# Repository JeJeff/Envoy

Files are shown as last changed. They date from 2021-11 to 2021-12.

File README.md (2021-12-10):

# Envoy
Envoy is a numberpad that can also be built as a 20 key macropad with support for four encoders. 
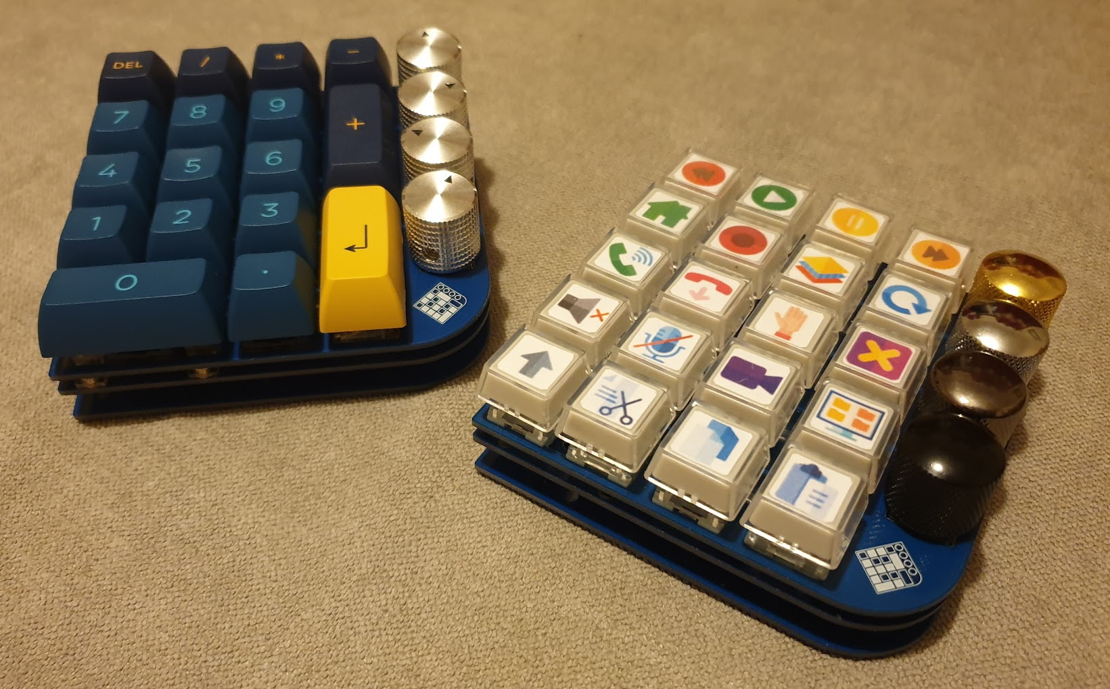
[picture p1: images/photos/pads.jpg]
Envoy numberpad and macropad


<details>
  <summary>Kicad images</summary>
  
 ### PCB Front
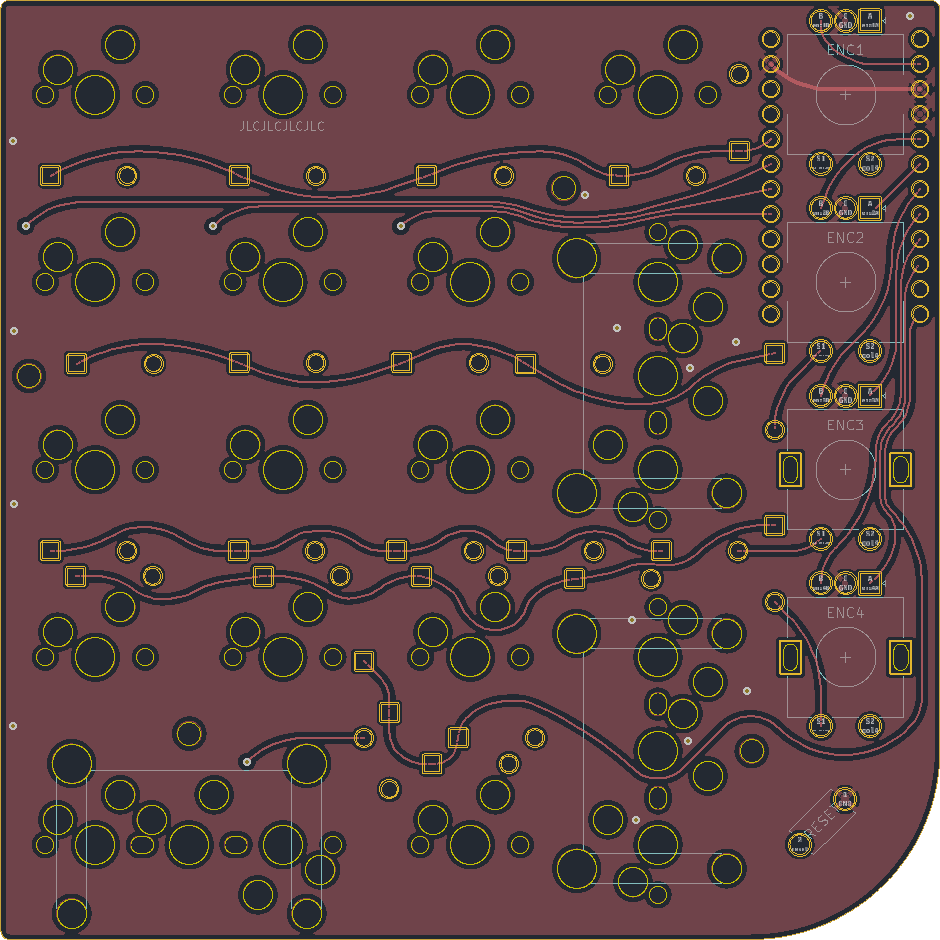
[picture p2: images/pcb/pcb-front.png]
Front of PCB
 
 
 ### PCB Back
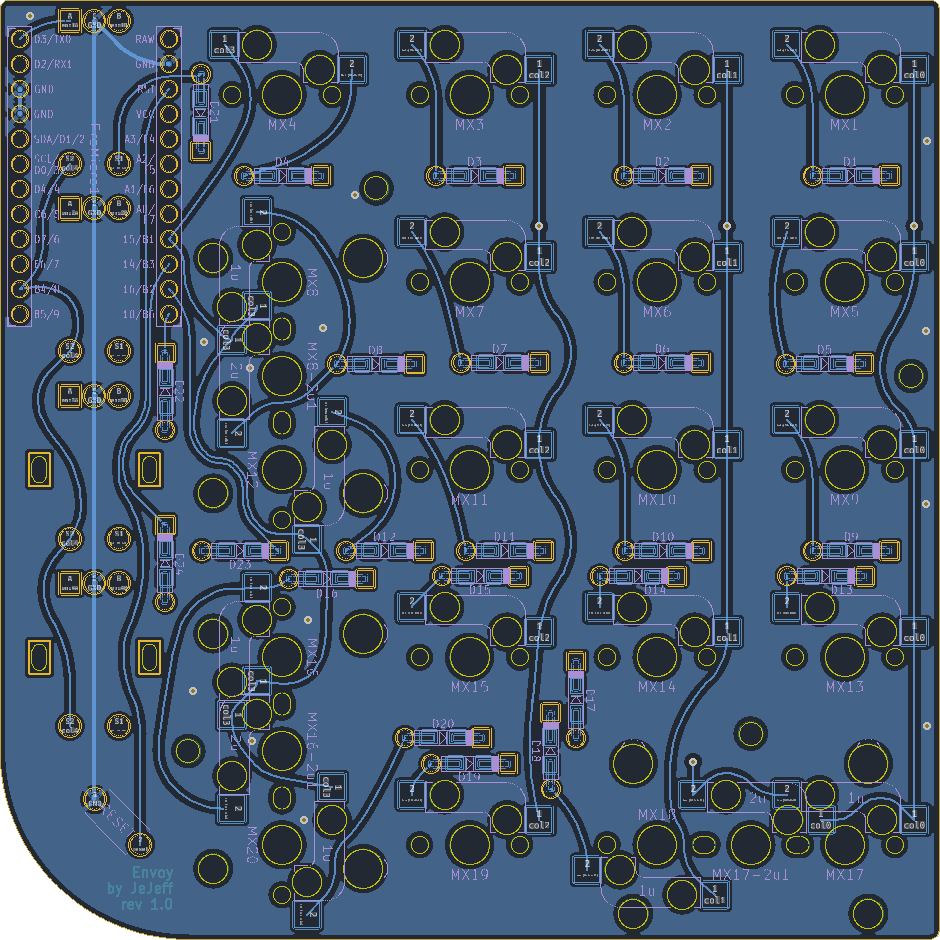
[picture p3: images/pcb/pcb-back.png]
Back of PCB
 
</details>

<details>
  <summary>PCB renders</summary>
  
 ### PCB Front
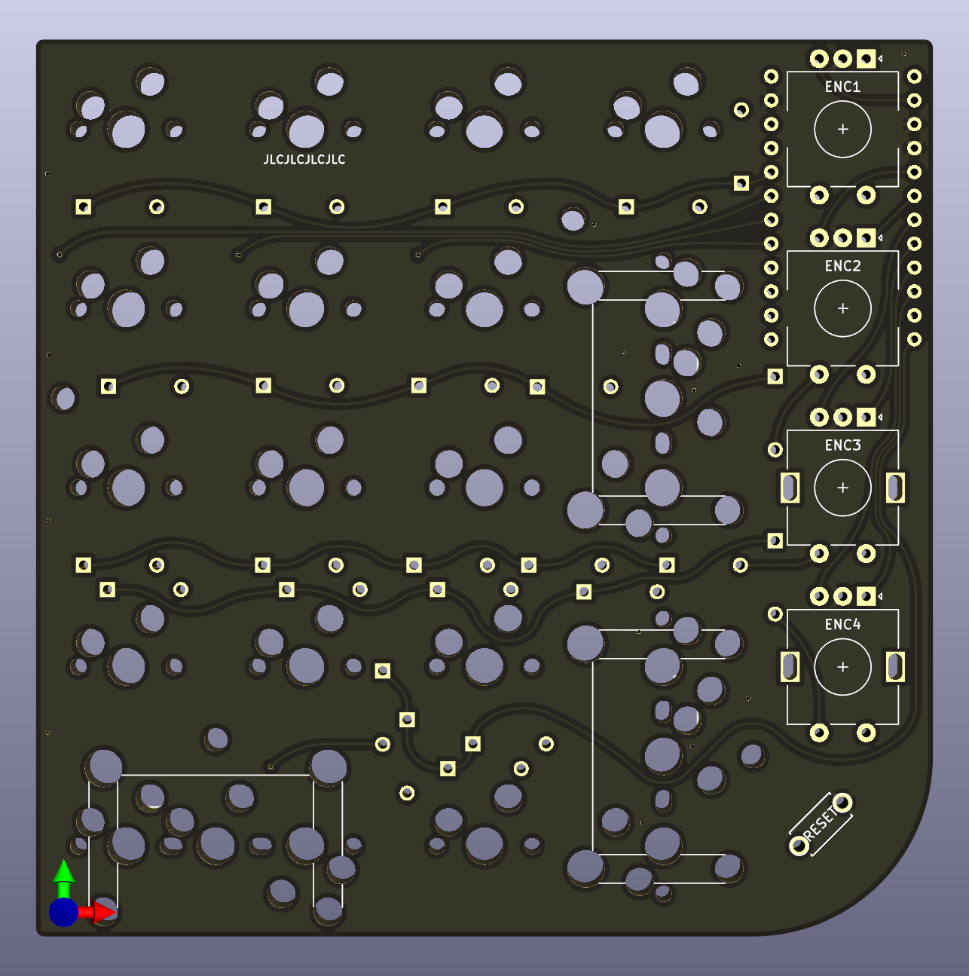
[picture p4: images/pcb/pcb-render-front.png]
Front of PCB
 
 
 ### PCB Back
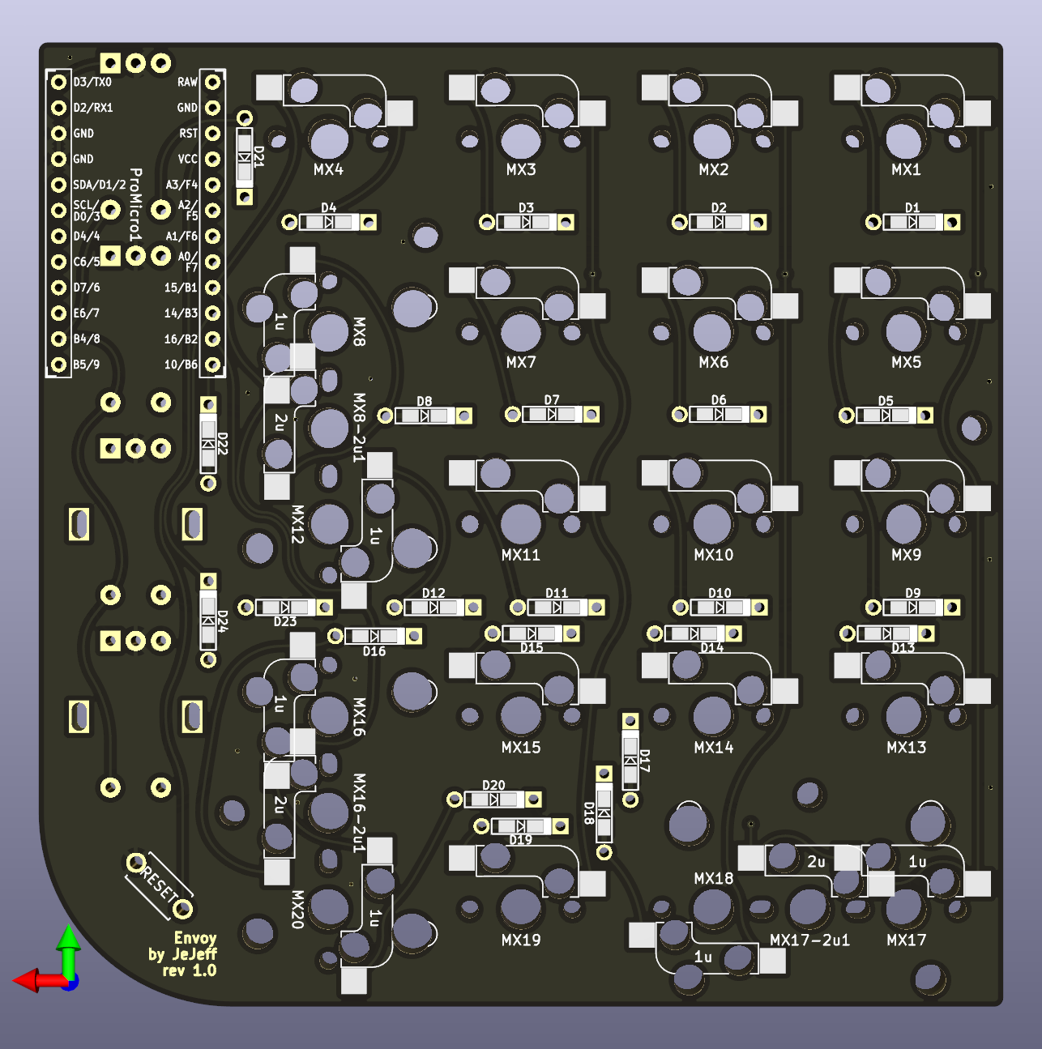
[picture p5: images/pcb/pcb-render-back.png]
Back of PCB
 
</details>

## Key features
* 20 key macro pad or standard number pad configuration
* Both 3 and 5 pin MX style switches supported
* Hot swap sockets
* Four rotary encoders
* QMK controlled
* Vial firmware
* Easy to solder

## Additional information
 * 2 layer PCB
 * Switch plate and back plate designs available
 * Both throughhole and SMD diodes supported
 
## Bill of materials
|Reference | Item | Quantity | Notes
|:---:|---|:---:|---
| | **Plates** | |
| | PCB | 1 |
| | Back plate | 1 | 
| | Switch plate | 1 | Technically optional, but recommended.
| | | |
| | **Components to solder** | |
| D1-D20 | 1N4148 Diode | 21-24 | Both SMD (SOD-123) and through hole (DO-35) supported.
| U1 | 12x1 male pin header | 2 | For the pro micro.
| U1 | Pro Micro | 1 | Or pin compatible controller.
| ENC1-ENC4| EC11 Rotary Encoder | 4 | 
| | | |
| | **Hardware** | |
| | Aluminium cone feet | 0 or 2 | If you want to raise the back and tilt the pad towards you.
| | M2 standoff 8mm | 4 | 
| | M2 x 6mm flat head screw | 8 | Button head screws also work, could go as short as 4mm.
| | Rubber feet 8mm diameter | 2 or 4 | Only 2 needed if also using the cone feet.
| | | |
| | **Keys and Knobs** | |
| | 2u Stabilizer | 0-3 | One required for each 2u key, 3 for a standard number pad configuration.
| | MX Switches | 17-20 | 
| | Keycaps | 17-20 | 
| | Encoder knob | 4 | Matching the encoder, max diameter 18mm.

## Build Guide
* [Long version with descriptions and tips](Build-Guide.md) 
* [Short version which is not much more than a list of steos](Build-Guide-Short.md)

## Firmware
[See the firmware flashing guide](Firmware/Firmware-Flashing.md)

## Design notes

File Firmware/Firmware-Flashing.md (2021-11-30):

### Envoy Firmware Flashing Guide
Use [QMK Toolbox](https://github.com/qmk/qmk_toolbox/releases) to flash the firmware.

1. Download the [recommended vial firmware here](https://github.com/JeJeff/Envoy/raw/main/Firmware/jejeff_envoy_vial.hex) (right click > save link as...). 
2. Open the QMK Toolbox application.
3. Under 'local file' select the downloaded jejeff_envoy_vial.hex file.
4. Set the MCU field to 'atmega32u4'.
5. Connect your the Pro Micro to your computer using USB.  You may need to wait whilst your operating system installs drivers.
6. Short the two 'reset' pins on the rounded corner of the PCB.  You could use tweezers, or a short length of wire.
7. You should see the yellow text that starts ```*** Caterina device connected``` appear
8. Click the 'Flash' button within 8 seconds.
9. Wait as QMK Toolbox reads the Pro Micro, writes the new firmware, then verifies it was successful.
10. Near the bottom you should get confirmation that it was verified successfully:
```
    avrdude.exe: verifying ...
    avrdude.exe: 24920 bytes of flash verified
    
    avrdude.exe done.  Thank you.
```
11. Your Envoy macro pad is now ready to be configured in [Vial](https://get.vial.today/).

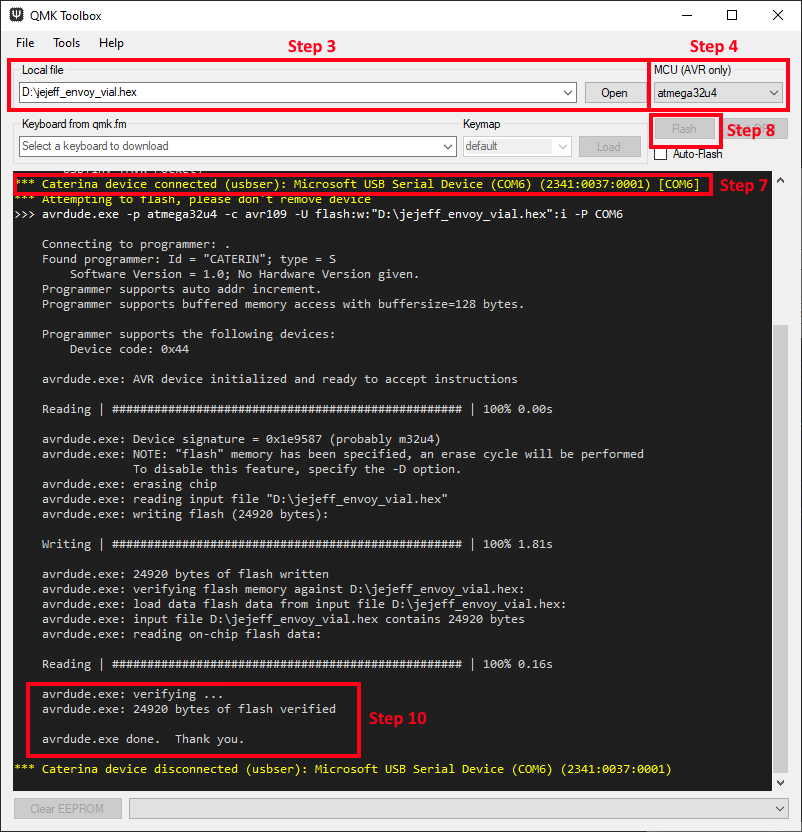
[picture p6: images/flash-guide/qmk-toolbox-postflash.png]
QMK Toolbox window annotated with the above steps


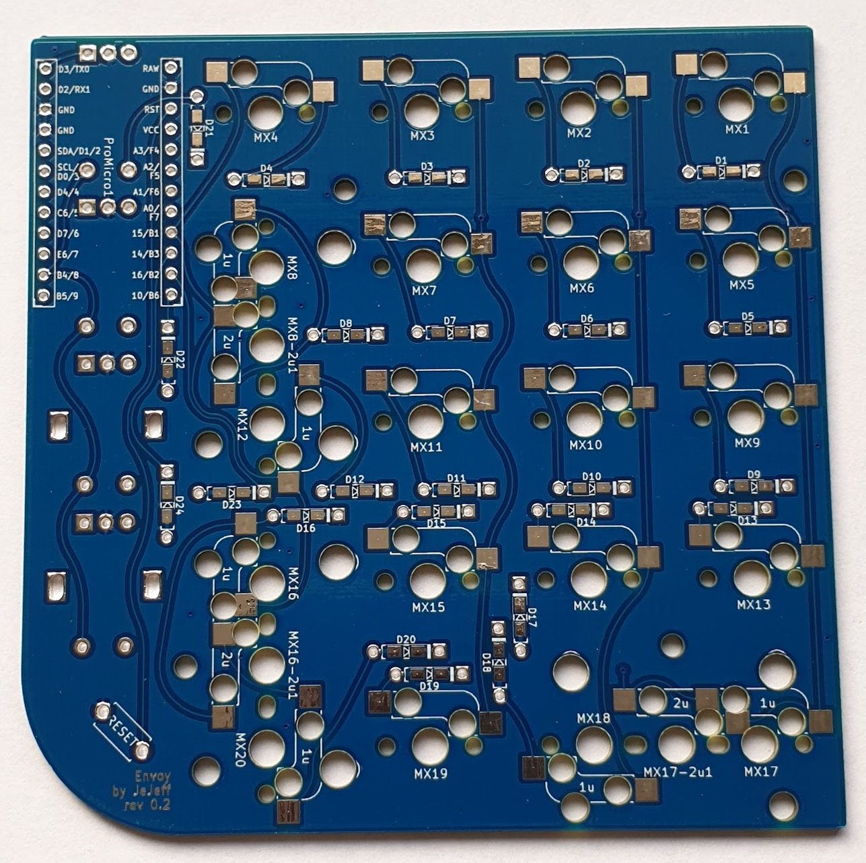
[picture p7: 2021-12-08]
images/photos/pcb-back.jpg

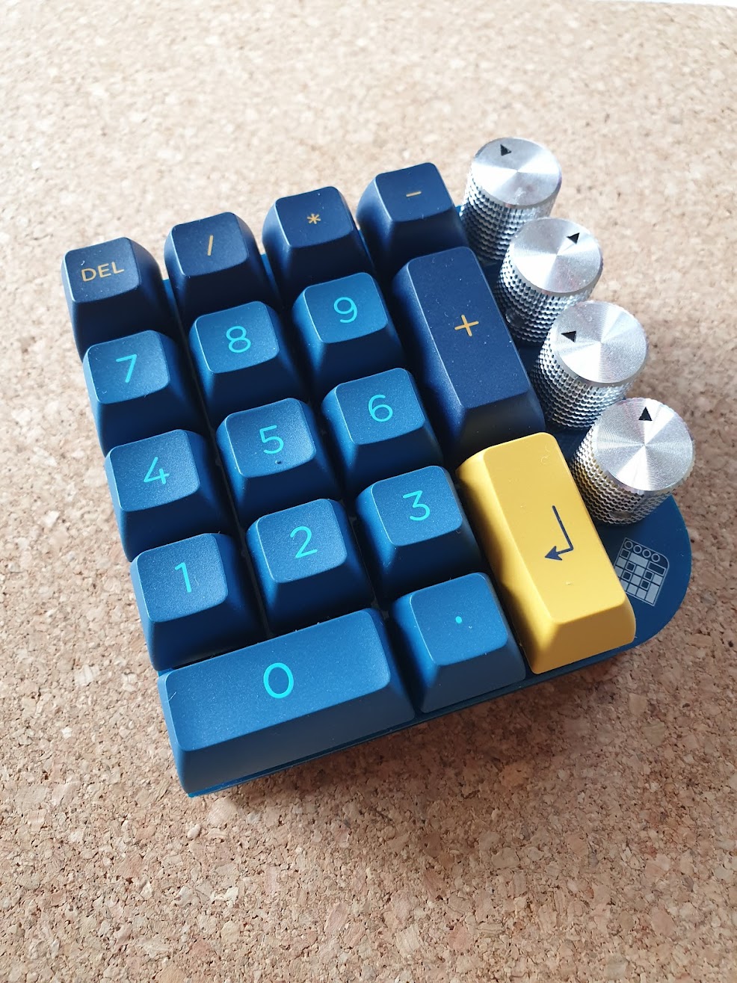
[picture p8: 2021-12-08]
images/photos/numberpad.jpg

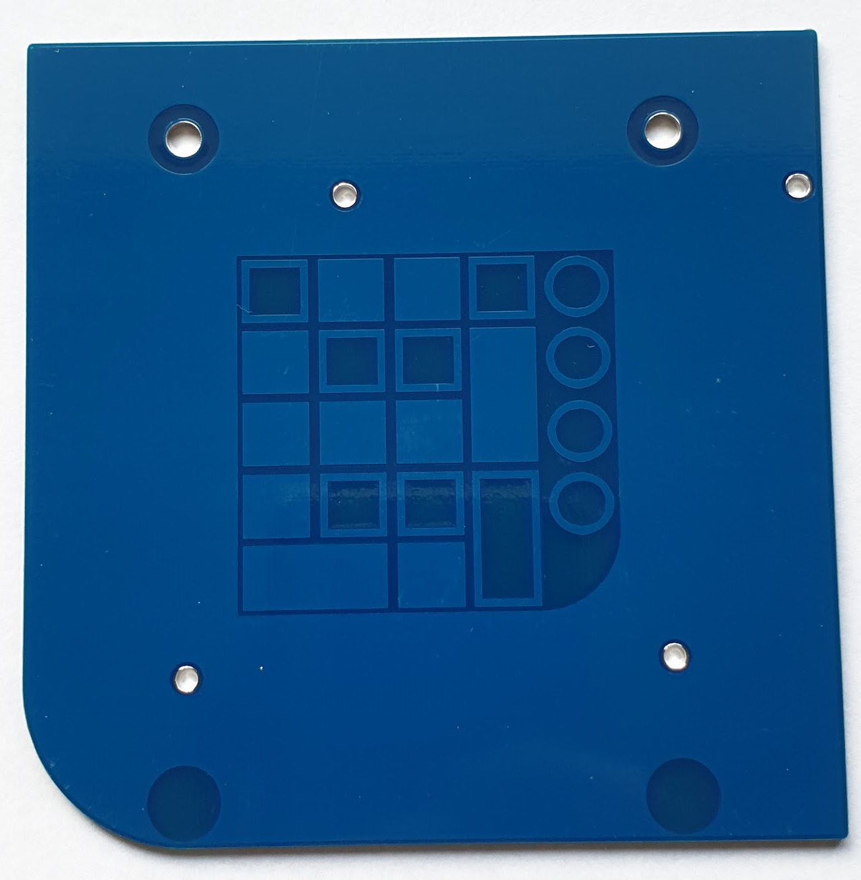
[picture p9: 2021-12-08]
images/photos/backplate-back.jpg

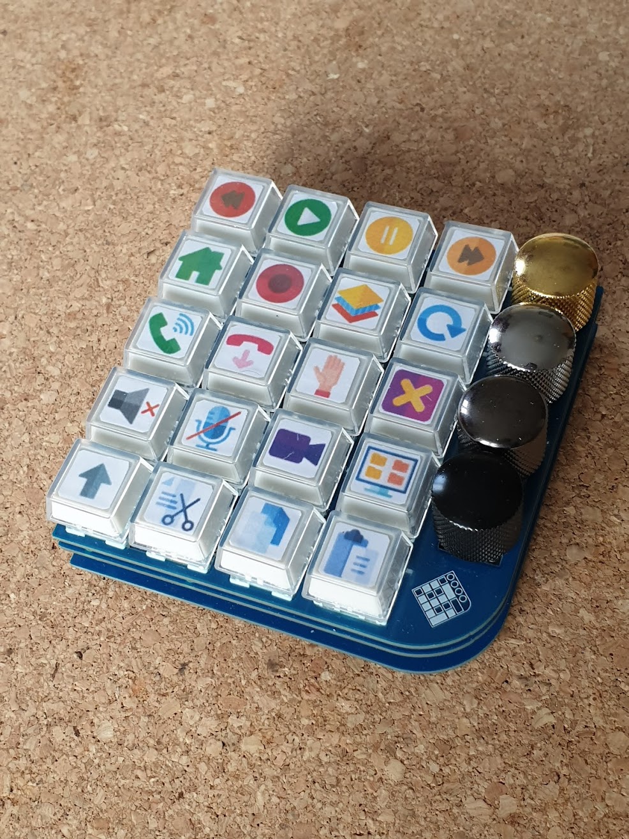
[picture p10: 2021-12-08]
images/photos/macropad.jpg

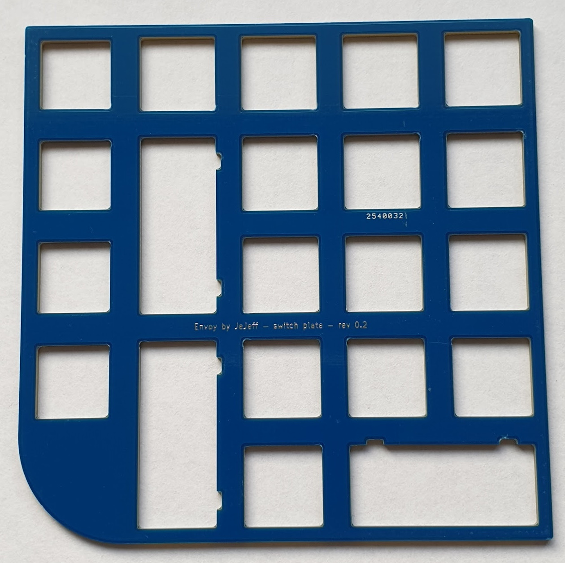
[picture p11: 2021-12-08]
images/photos/switchplate-back.jpg

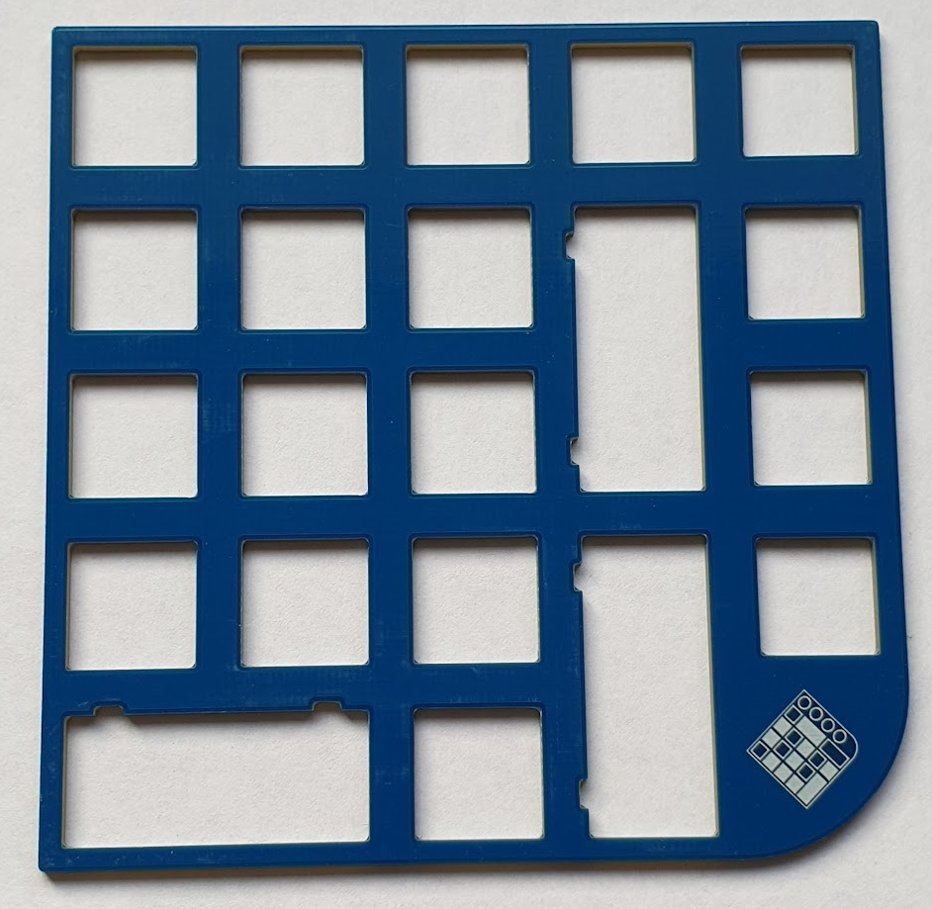
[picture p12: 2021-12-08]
images/photos/switchplate-front.jpg

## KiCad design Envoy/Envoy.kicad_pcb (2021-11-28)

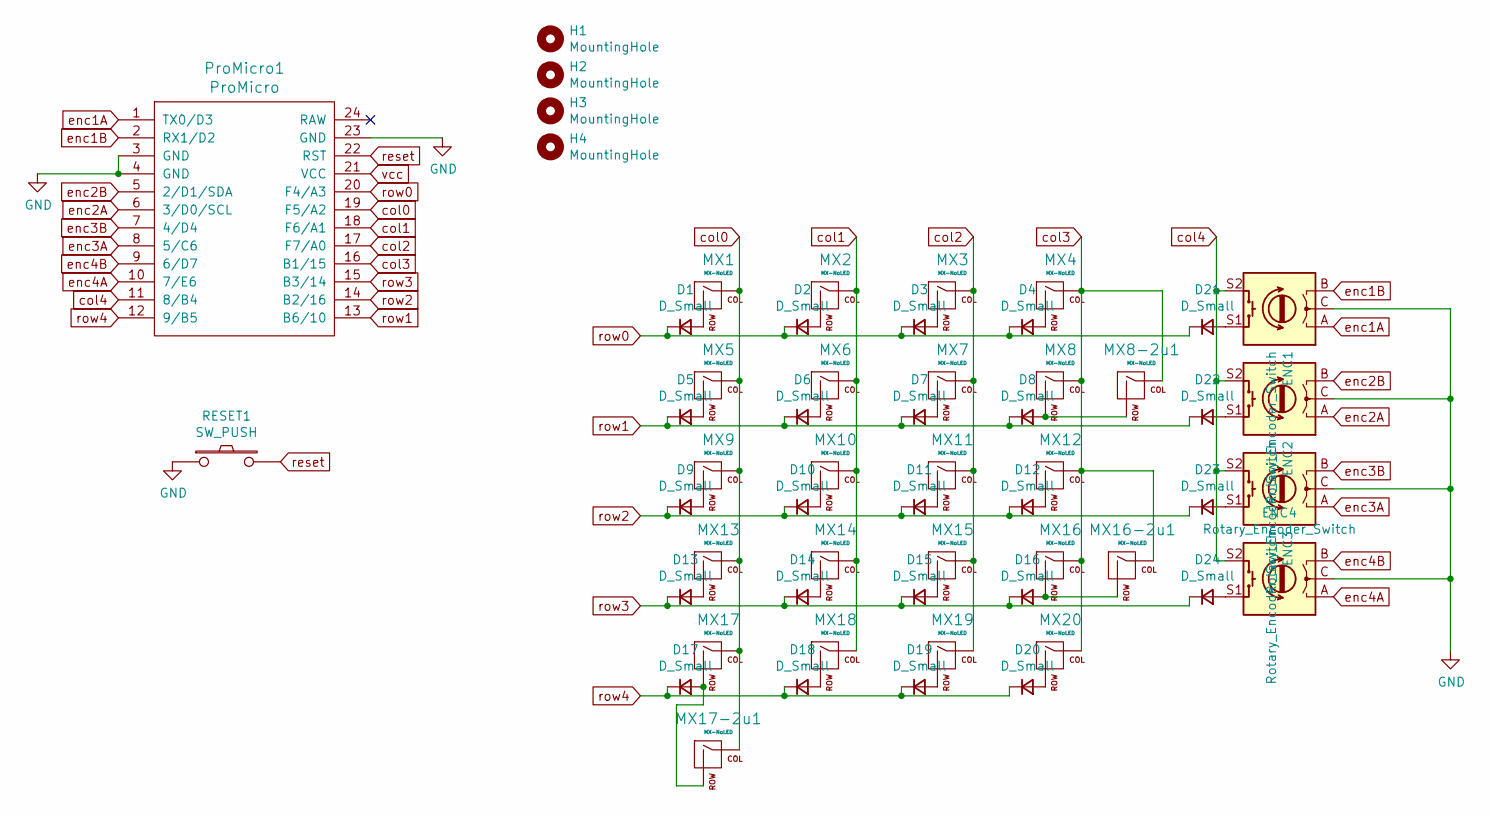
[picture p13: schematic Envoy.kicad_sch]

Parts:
D1, D2, D3, D4, D5, D6, D7, D8, D9, D10, D11, D12, D13, D14, D15, D16, D17, D18, D19, D20, D21, D22, D23, D24: D_Small; Diode-Hybrid-Back
ENC1, ENC2: Rotary_Encoder_Switch; RotaryEncoder_EC11-no-legs
ENC3, ENC4: Rotary_Encoder_Switch; RotaryEncoder_EC11
H1, H2, H3, H4: MountingHole; MountingHole_2.5mm
MX1, MX2, MX3, MX5, MX6, MX7, MX9, MX10, MX11, MX13, MX14, MX15, MX19: MX-NoLED; MXOnly-1U-Hotswap
MX4: MX-NoLED; MXOnly-1U-HotswapReversed
MX8, MX12, MX16, MX17: MX-NoLED; MXOnly-1U-Hotswap-2KeyAlternativeLeft
MX8-2u1, MX16-2u1: MX-NoLED; MXOnly-2U-Hotswap-2KeyAlternative
MX17-2u1: MX-NoLED; MXOnly-2U-Hotswap-ReversedStabilizers-Alternative
MX18, MX20: MX-NoLED; MXOnly-1U-HotswapReversed-2KeyAlternativeLeft
ProMicro1: ProMicro; ProMicro_v3
RESET1: SW_PUSH; ResetSW

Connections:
GND: ENC1.C, ENC2.C, ENC3.C, ENC4.C, ProMicro1.3 (GND), ProMicro1.4 (GND), ProMicro1.23 (GND), RESET1.1
unnamed: D1.2 (A), MX1.2 (ROW)
unnamed: D2.2 (A), MX2.2 (ROW)
unnamed: D3.2 (A), MX3.2 (ROW)
unnamed: D4.2 (A), MX4.2 (ROW)
unnamed: D5.2 (A), MX5.2 (ROW)
unnamed: D6.2 (A), MX6.2 (ROW)
unnamed: D7.2 (A), MX7.2 (ROW)
unnamed: D8.2 (A), MX8.2 (ROW), MX8-2u1.2 (ROW)
unnamed: D9.2 (A), MX9.2 (ROW)
unnamed: D10.2 (A), MX10.2 (ROW)
unnamed: D11.2 (A), MX11.2 (ROW)
unnamed: D12.2 (A), MX12.2 (ROW)
unnamed: D13.2 (A), MX13.2 (ROW)
unnamed: D14.2 (A), MX14.2 (ROW)
unnamed: D15.2 (A), MX15.2 (ROW)
unnamed: D16.2 (A), MX16.2 (ROW), MX16-2u1.2 (ROW)
unnamed: D17.2 (A), MX17.2 (ROW), MX17-2u1.2 (ROW)
unnamed: D18.2 (A), MX18.2 (ROW)
unnamed: D19.2 (A), MX19.2 (ROW)
unnamed: D20.2 (A), MX20.2 (ROW)
unnamed: D21.2 (A), ENC1.S1
unnamed: D22.2 (A), ENC2.S1
unnamed: D23.2 (A), ENC3.S1
unnamed: D24.2 (A), ENC4.S1
col0: MX1.1 (COL), MX5.1 (COL), MX9.1 (COL), MX13.1 (COL), MX17.1 (COL), MX17-2u1.1 (COL), ProMicro1.19 (F5/A2)
col1: MX2.1 (COL), MX6.1 (COL), MX10.1 (COL), MX14.1 (COL), MX18.1 (COL), ProMicro1.18 (F6/A1)
col2: MX3.1 (COL), MX7.1 (COL), MX11.1 (COL), MX15.1 (COL), MX19.1 (COL), ProMicro1.17 (F7/A0)
col3: MX4.1 (COL), MX8.1 (COL), MX8-2u1.1 (COL), MX12.1 (COL), MX16.1 (COL), MX16-2u1.1 (COL), MX20.1 (COL), ProMicro1.16 (B1/15)
col4: ENC1.S2, ENC2.S2, ENC3.S2, ENC4.S2, ProMicro1.11 (8/B4)
enc1A: ENC1.A, ProMicro1.1 (TX0/D3)
enc1B: ENC1.B, ProMicro1.2 (RX1/D2)
enc2A: ENC2.A, ProMicro1.6 (3/D0/SCL)
enc2B: ENC2.B, ProMicro1.5 (2/D1/SDA)
enc3A: ENC3.A, ProMicro1.8 (5/C6)
enc3B: ENC3.B, ProMicro1.7 (4/D4)
enc4A: ENC4.A, ProMicro1.10 (7/E6)
enc4B: ENC4.B, ProMicro1.9 (6/D7)
reset: ProMicro1.22 (RST), RESET1.2
row0: D1.1 (K), D2.1 (K), D3.1 (K), D4.1 (K), D21.1 (K), ProMicro1.20 (F4/A3)
row1: D5.1 (K), D6.1 (K), D7.1 (K), D8.1 (K), D22.1 (K), ProMicro1.13 (B6/10)
row2: D9.1 (K), D10.1 (K), D11.1 (K), D12.1 (K), D23.1 (K), ProMicro1.14 (B2/16)
row3: D13.1 (K), D14.1 (K), D15.1 (K), D16.1 (K), D24.1 (K), ProMicro1.15 (B3/14)
row4: D17.1 (K), D18.1 (K), D19.1 (K), D20.1 (K), ProMicro1.12 (9/B5)
vcc: ProMicro1.21 (VCC)

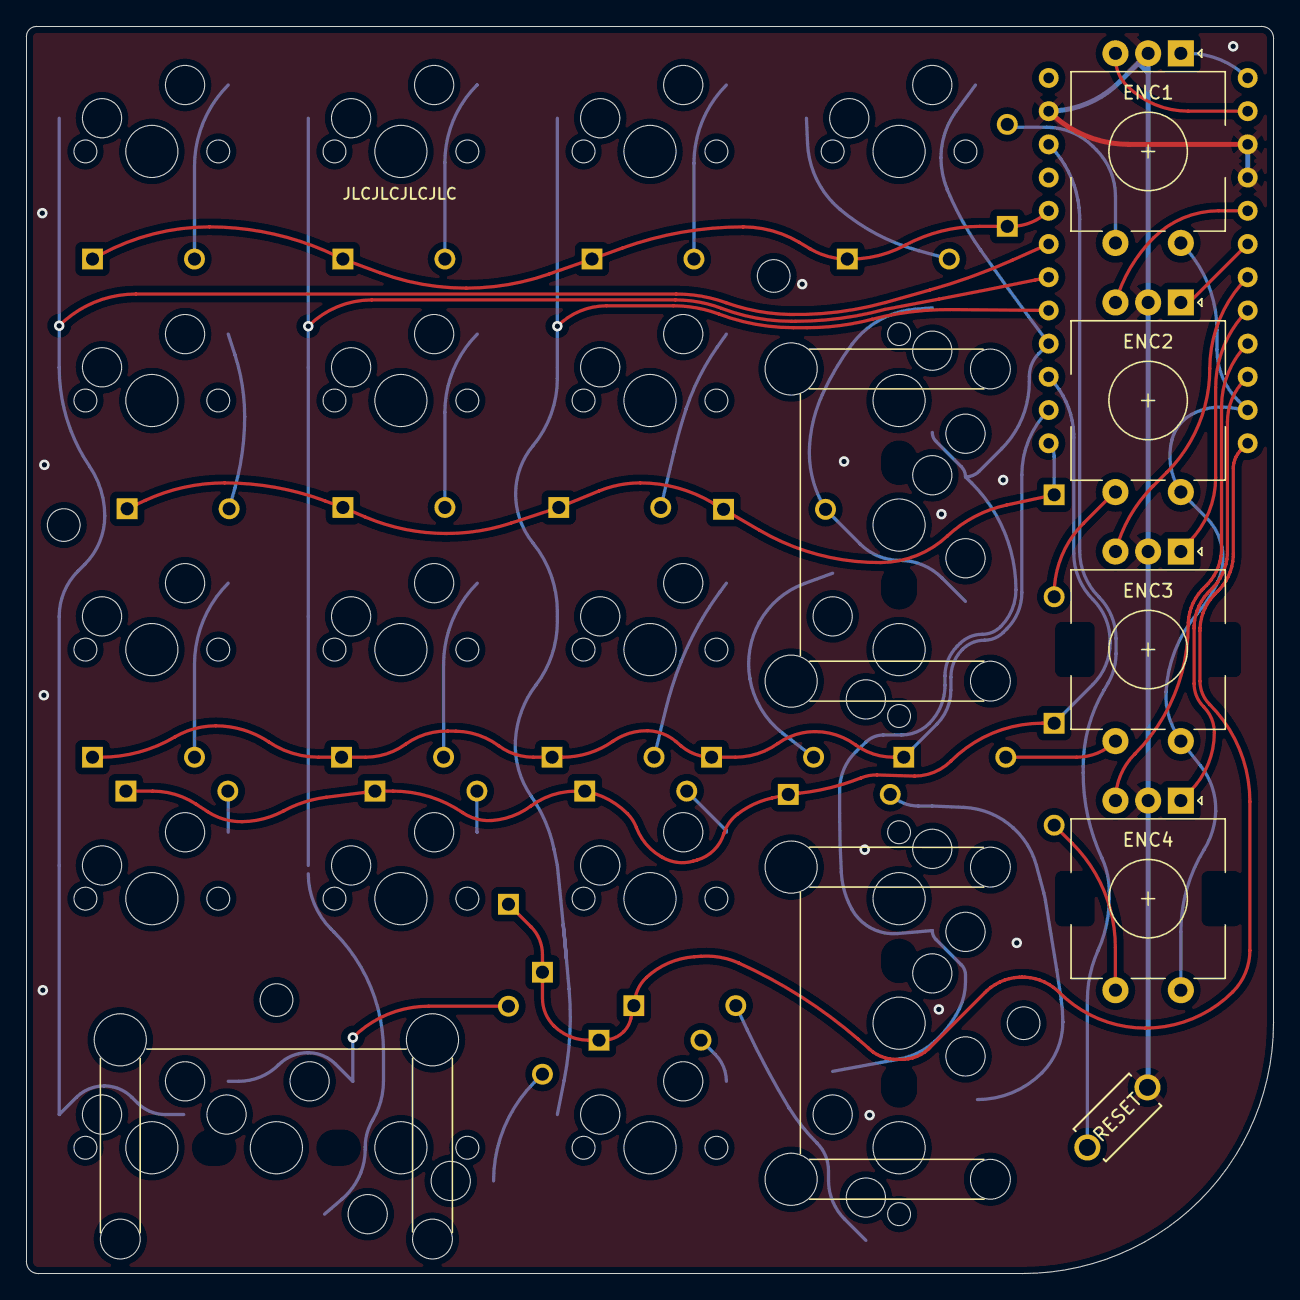
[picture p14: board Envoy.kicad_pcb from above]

Board: 2 copper layers, 95.4 x 95.4 mm, 57 parts (0 on the bottom side), 44 nets.

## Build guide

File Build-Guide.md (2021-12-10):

# Envoy macro pad build guide

This is the long version of the build guide.  If you know what you are doing and just want a simple build order you could use [the short version of the build guide](Build-Guide-Short.md).

## General instructions
- All components will be soldered on the side with the related silk screen markings.
  - This means only encoders are placed on the front of the board.
  - All other components (diodes, hotswap sockets, pro micro) are placed on the back of the board
- This guide sometimes needs to refer to particular keys.  It will reference a standard layout number pad to identify key locations where this is necessary.

## Step 1 - Choose your layout
The Envoy supports a number pad layout, with double size (2u) zero, plus and enter keys, but all of these 2u keys can also be split into two single (1u) keys.  As a few examples, this means you could have:
- A standard number pad
- A number pad with the zero split into '0' and '00' keys
- 20 individual keys to use however you want

## Step 2 - Diodes
If you are using and double sized (2u) keys then you can skip some diodes.
- A 2u plus key means you can skip D12
- A 2u enter key means you can skip D20
- a 2u zero key means you can skip D18

(If you solder in these diodes but do not use the matching key switch it will not cause any problems).

If using through hole diodes, then continue with step 2.1.

If using only SMD diodes, then skip to step 2.2.

### Step 2.1 - Soldering through hole diodes
___NOTE: Diodes have a polarity.  They must be connected the correct way round.___

__If using through hole diodes the polarity is marked by the black line going around the diode body.__

__The line must be nearest the square pad.  The arrow in the silk screen markings points at the black line on the diode.__

- Bend the diode legs close to the body to fit the hole spacing and insert diodes D1-D24 from the back of the board.  
- Double check the polarity.  
- Flip the board over so you can see the front (you may wish to use tape to hold the diodes in place).
- Solder all the diodes.
- Clip the legs close to the board.
  
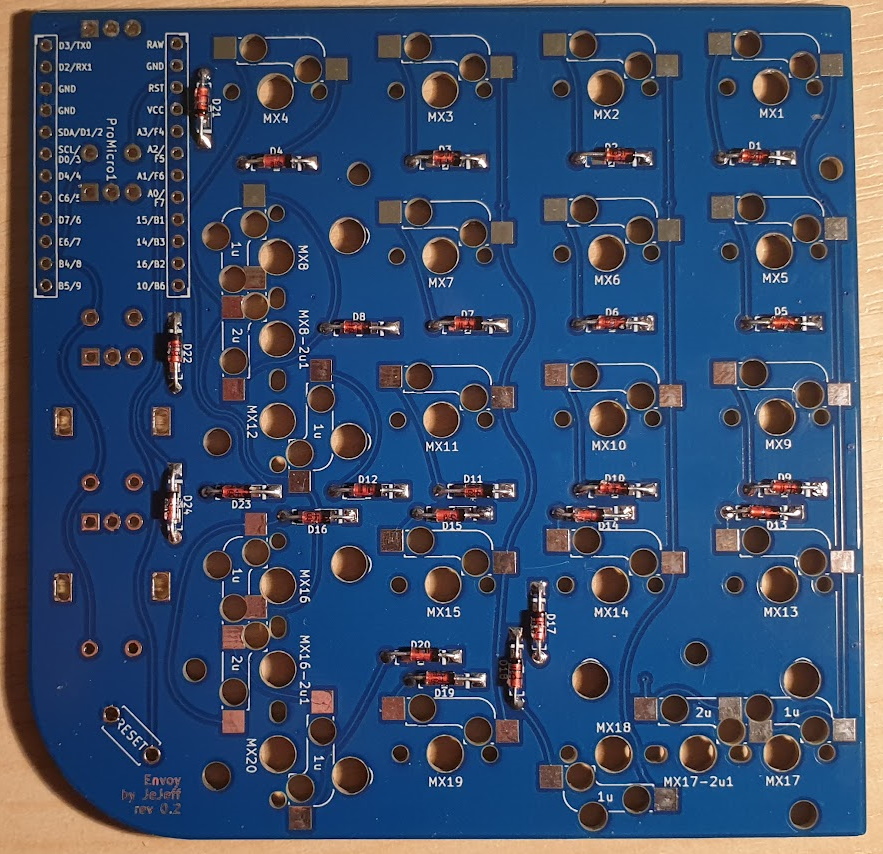
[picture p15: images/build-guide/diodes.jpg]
Through hole diodes on an Envoy PCB

  
### Step 2.2 - Soldering SMD diodes
___NOTE: Diodes have a  polarity.  They must be connected the correct way round.___

__If using SMD diodes the polarity is indicated by a line on the diode body.  This line can be very hard to see.  Use magnification and good lighting, and check every diode before placement__

__The line must be nearest the square pad.  The arrow in the silk screen markings points at the line on the diode.__

- Tin one of the SMD pads for each diode D1-D24.
- Hold each diode in place using tweezers and heat the pad whilst pushing the diode down so it settles into place.
- Double check the polarity (it is much easier to fix problems without both ends being soldered).
- Solder the other pad of each diode.

## Step 3 - Hotswap sockets
_If you prefer to check functionality with the minimum components in place you could delay most of this step until after Step 8, but soldering MX4 now is recommended as the Pro Micro headers will obstruct access to solder MX4 later on._

You must use the correct socket placement for your required layout.  This should be obvious from looking at the board, but for completeness:

 Key Location   | 2u (not split)     | 1u + 1u (split)
 ---------------|--------------------|----------------
 Plus           | Skip MX8 and MX12  | Skip MX8-2u1
 Enter          | Skip MX16 and MX10 | Skip MX16-2u1
 Zero           | Skip MX17 and MX18 | Skip MX17-2u1
 
### Step 3.1 - Soldering hotswap sockets
- Place sockets on the back of the board in all required locations MX1-MX20.
- Solder one end of each socket.
- Reheat the soldered joint whilst pushing down on the socket to ensure it is properly seated.
- Inspect sockets from the other side of the board to double check they are properly flat (it is much easier to fix problems without both ends being soldered).
- Solder the other end of each socket

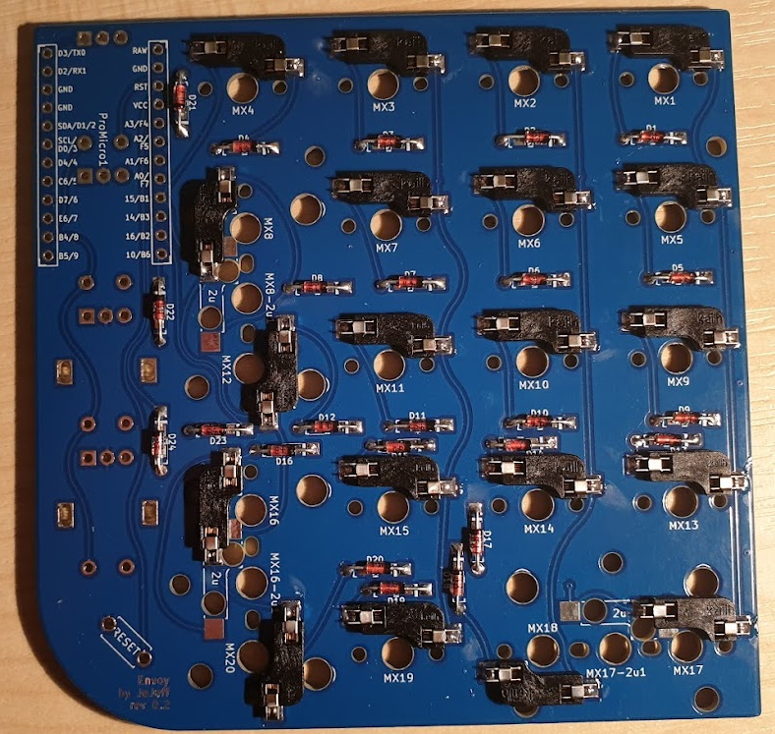
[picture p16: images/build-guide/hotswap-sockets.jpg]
Hotswap sockets on an Envoy PCB


## Step 4 - Solder Pro Micro headers
- Insert the short end of both pin headers into the back of the board, and place the Pro Micro over the longer end to ensure good alignment.
- Flip the board over so you can see the front.
- Solder one pin on each header.
- Inspect and check that each header is properly seated and flush with the board, and that the Pro Micro fits nicely.  Reheat the soldered joint whilst pushing the header down to realign things if necessary.
- Remove the Pro Micro.
- Solder the rest of the pins.  To avoid overheating and melting the plastic either alternate sides, or solder every other pin and then go back for the rest.

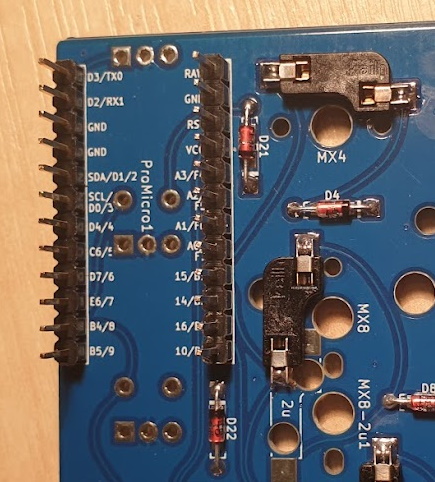
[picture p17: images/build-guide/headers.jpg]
Headers for the Pro Micro on an Envoy PCB


## Step 5 - Encoders
You will need to remove the side legs from your encoder housing for ENC1 and ENC2.  This can be done by grabbing with pliers and bending back and forth until it just comes off through metal fatigue
### Step 5.1 - Soldering encoders
- Insert each encoder from the front of the board into positions ENC1-ENC4.
- Solder one pin on each encoder.
- Inspect and check that each encoder is properly seated and flush with the board.  Reheat the soldered joint whilst pushing the encoder down to realign things if necessary.
- Solder the remaining pins

## Step 6 - Flash the Pro Micro 
It can be a good idea to make sure the Pro Micro is in good condition before soldering it in place, so connect it to your computer and [flash your firmware of choice](Firmware/Firmware-Flashing.md). 

## Step 7 - Solder Pro Micro
- Place the Pro Micro on the headers.  The components on the Pro Micro should face away from the Envoy PCB.
- Check that none of the encoder pins are touching the pro micro.  Trim them if necessary.
- Solder all the Pro Micro pins.  To avoid overheating either alternate sides, or solder every other pin and then go back for the rest.
- Clip the protruding header pins so the backplate can fit.  Use good strong wire cutters for this, or at least accept that your flush cutters may get damaged.  Pin headers are much larger and stronger than diode legs.

## Step 8 - Check operation
At this point everything required for basic operation is in place.  Check operation by using tweezers to short the pads for each keyswitch.

## Step 9 - Key stabilizers
Each 2u key should have a PCB mount stabilizer added.
- Insert the legs from the side where the stabilizer wire is into the larger hole, then the other end (where the screw thread is for screw in stabilizers) into the smaller hole
- Inspect and make sure each stabilizer housing is fully inserted and flush with the board.
- Secure with screws if not using clip-in stabilizers.

## Step 10 - Standoffs
There are four unmarked holes in the PCB.  They are easy to identify as they match up with the four small holes in the backplate.
- Attach a 6mm standoff to the back of the PCB at each of these holes by using a flat head M2 screw.

## Step 11 - Switches
- Place the first switch into the switch plate.
- Carefully push the switch pins into the matching hotswap socket.
- Now add the second switch.  You will probably need to use a small brush handle or similar to push the switch plate up onto the switch as the switch goes into the socket.
- Repeat until all the switches are in place.

## Step 12 - Backplate
- If you are using them, attach the cone feet to the bottom of the back plate.
- Add rubber bumpers to the opposite end of the back plate into the marked locations.
- Align the backplate with the standoffs and attach with M2 screws.

## Step 13 - Key caps
- Add your keycaps and encoder knobs of choice, and sit back with a sense of satisfaction.

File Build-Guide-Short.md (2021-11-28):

# Envoy macro pad build guide

This is the short and sweet version of the build guide.  If you want more description and tips, please see [the long version of the build guide](Build-Guide.md).

## General instructions
- All components will be soldered on the side with the related silk screen markings.
- This guide sometimes needs to refer to particular keys.  It will reference a standard layout number pad to identify key locations where this is necessary.

### Skippable Components
 Key Location   | 2u (not split)          | 1u + 1u (split)
 ---------------|-------------------------|----------------
 Plus           | Skip D12, MX8 and MX12  | Skip MX8-2u1
 Enter          | Skip D20, MX16 and MX10 | Skip MX16-2u1
 Zero           | Skip D18, MX17 and MX18 | Skip MX17-2u1

## Build order
1. Diodes D1-D24.  
   - ___NOTE: Diodes have a  polarity.  They must be connected the correct way round.___
2. Hotswap sockets MX1-MX20.
3. Pro Micro Headers ProMicro1.
4. Encoders ENC1-ENC4. 
   - Remove the side legs from your encoder housing for ENC1 and ENC2.
5. Pro Micro onto headers.
   - Clip the Pro Micro headers to size after soldering so the backplate can fit.
6. Check operation.
7. 2u Stabilizers where needed.
8. Attach standoffs to PCB (M2 screws).
9. Switches into switchplate and PCB.
10. Attach feet to backplate.
11. Attach backplate to PCB via standoffs (M2 screws).
12. Add keycaps and encoder knobs.

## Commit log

2021-09-27 First draft done
    [Envoy.kicad_pcb, Envoy.sch]
2021-10-22 Rev 0.2 including switchplate and backplate
    [Envoy-B_Cu.gbl, Envoy-B_Mask.gbs, Envoy-B_Paste.gbp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]
2021-11-01 Fix switchplate cutout sizes
    [Envoy-Switchplate.kicad_pcb]
2021-11-01 Move standoff and bumper positioning to make the backplate work easier
    [Envoy-Backplate.kicad_pcb, Envoy-Switchplate.kicad_pcb, Envoy.kicad_pcb]
2021-11-01 Fix logo on switchplate
    [Envoy-Switchplate.kicad_pcb]
2021-11-01 add PCB identifier
    [Envoy-Backplate.kicad_pcb, Envoy-Switchplate.kicad_pcb]
2021-11-03 More tweaks to the switchplate cutouts, make switchplate float instead of the PCB, move diodes to give more space to stabs
    [Envoy-Backplate.kicad_pcb, Envoy-Switchplate.kicad_pcb, Envoy-skewed.kicad_pcb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]
2021-11-03 Moved most diodes to horizontal layout to enable better access for soldering hotswap sockets
    [Envoy.kicad_pcb]
2021-11-03 Increasxed line width in small envoy icon
    [Envoy-Switchplate.kicad_pcb, Envoy.kicad_pcb]
2021-11-08 curves! Fun curved traces. Prepare rev0.2 gerbers
    [Envoy-B_Cu.gbl, Envoy-B_Mask.gbs, Envoy-B_Paste.gbp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]
2021-11-26 Moved feet outwards a bit for additional stability
    [Envoy-Backplate.kicad_pcb]
2021-11-26 Widen feet placement a little more. Bump revision to 1.0
    [Envoy-Backplate.kicad_pcb]
2021-11-27 Moved a standoff hole and the feet. Bumped pcb revision to 1.0
    [Envoy-Backplate.kicad_pcb, Envoy.kicad_pcb]
2021-11-27 Bumped switchplate revision to 1.0. No design changes from rev 0.2.
    [Envoy-Switchplate.kicad_pcb]
2021-11-27 Final feet position
    [Envoy-Backplate.kicad_pcb]
2021-11-28 Make font slightly bolder so the HASL finish stands more chance of sticking.
    [Envoy-Backplate.kicad_pcb, Envoy-Backplate.kicad_sch, Envoy-Switchplate.kicad_pcb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]
2021-12-02 6mm standoffs were too short. Modified to 8mm
2021-12-09 added pcb images
2021-12-10 update pcb images
